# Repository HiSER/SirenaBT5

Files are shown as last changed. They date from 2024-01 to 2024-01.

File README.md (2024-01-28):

### Car music SirenaBT5
Приект выпущен по MIT лицензии, каждый кто использует проект, использует его на свой страх и риск, автор ответственности не несёт.
Проект выпущен как есть, без дальнейшей поддержки.

The project is published under the MIT license, everyone who uses the project uses it at their own peril and risk, the author does not bear responsibility.
The project is being released as is, no future support.

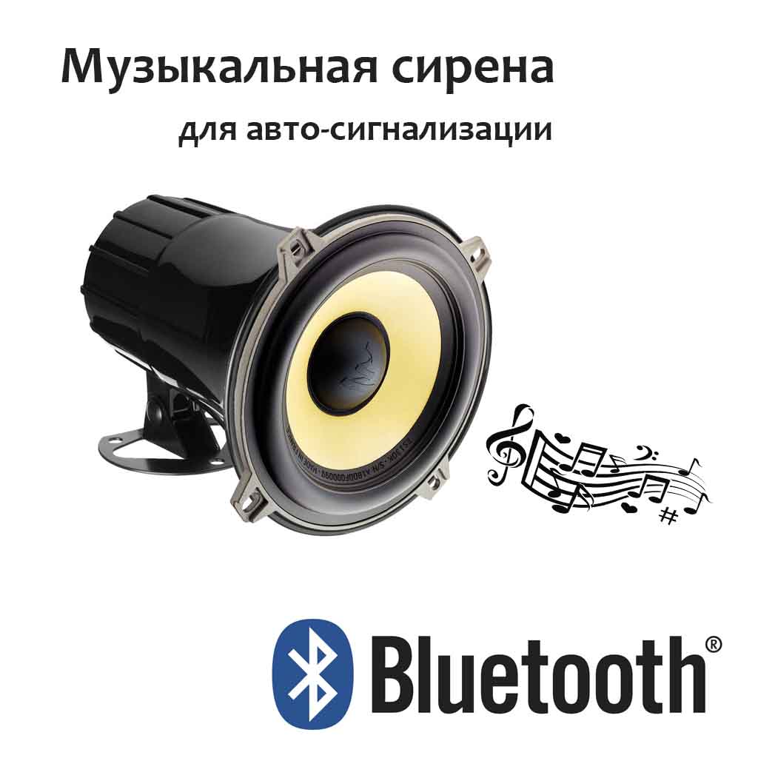
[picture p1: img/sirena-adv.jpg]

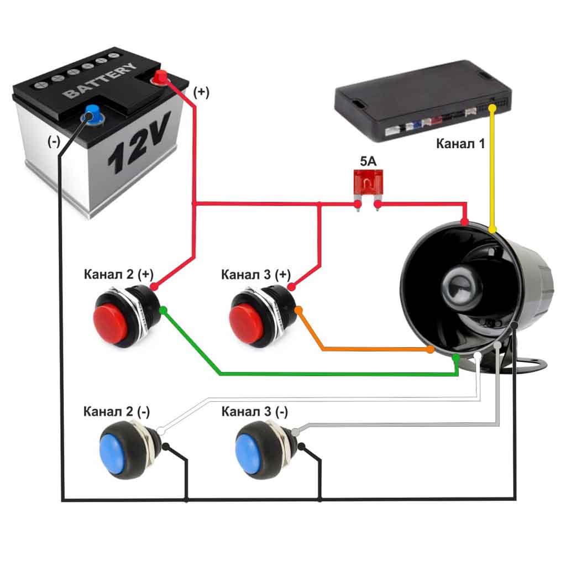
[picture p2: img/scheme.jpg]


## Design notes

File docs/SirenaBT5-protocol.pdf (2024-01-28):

# SirenaBT5

## Описание протокола обмена

### 2 SirenaBT5

Принцип работы

Протокол обмена SirenaBT5 аналогичен протоколу AT. Формат данных текстовой, каждая строка заканчивается символом CRLF. Канал связи работает в полном дуплексе. Некоторые ответы могут приходить без предварительного запроса командой. Команды требовательны к регистру символов. Канал связи BlueTooth профиль SPP-C (виртуальный COM порт). Команды можно отправлять подряд, не дождавшись ответа, буфер составляет 2048 байт.

Формат команды:

[команда][CRLF]

[команда]=[аргументы][CRLF]

Несколько аргументов разделяются символом ;

Формат ответа:

+[команда]:[ответ][CRLF]

Ответ может содержать:

- ключевые слова: OK, ERROR, BUSY, READY, NULL, TRUE, FALSE
- аргументы разделённые символом ;
- ключевое слово совместно с аргументом
- JSON

### 3 SirenaBT5

Список команд

- SPEAK
- PLAY*
- PLAYSTOP*
- LIST*
- GETMELODY*
- SETMELODY*
- DATAMELODY*
- ENDMELODY*
- DELETEMELODY*
- CLEARMELODY*
- GETEVENT*
- SETEVENT*
- DELETEEVENT*
- CLEAREVENT*
- SAVEFS*
- FS
- INFO
- GETCONFIG
- SETCONFIG
- SETBUTTON
- SETMEASURE
- SETPRESSMAX
- SETIDLEMAX
- SETDEVIATION
- PINCODE
- SAVECONFIG

*Команды зависят от состояния файловой системы

### 4 SirenaBT5

Список асинхронных ответов

- +FS
- +EVENT
- +PLAYSTOP

### 5 SirenaBT5

Команда SPEAK

Воспроизведение потокового аудио
Формат потока WAVE 8kHz 8bit, закодирован для передачи в WAVE7.

Команда записывает семплы в буфер и тут же начинает воспроизведение, воспроизведение продолжается до опустошения буфера. В ответе приходит количество записанных семплов в буфер, если количество записанных семплов меньше, чем было отправлено, то необходимо повторно отправить не записанные семплы. Порядок семплов слева на право.

Рекомендуется отправлять семплы пакетами по 1024 байт, размер пакета считается в незакодированном виде.

Отправка производится последовательно запрос/ответ, до тех пор, пока не закончатся аудио данные.

Запрос:

SPEAK=<семплы в кодировке WAVE7>

Ответ:

+SPEAK: {"writed":<записано семплов>}

### 6 SirenaBT5

Команда PLAY

Воспроизведение записанной мелодии
Доступные индексы узнаются командой LIST.

Ответ приходит при начале воспроизведения и конце воспроизведения.

Ответ +PLAYSTOP приходит без запроса.

Запрос:

PLAY =<index>

Ответ:

+PLAY: {"index":<index>}

+PLAYSTOP: {"index":<index>}

### 7 SirenaBT5

Команда PLAYSTOP

Остановить воспроизведение мелодии
Останавливает воспроизведение мелодии.

Если воспроизведения не было, то ответ с числом мелодии не придёт.

Запрос:

PLAYSTOP

Ответ:

+PLAYSTOP:OK

+PLAYSTOP: {"index":<index>}

### 8 SirenaBT5

Команда LIST

Запрос таблиц мелодий и событий
Возвращает массивы индексов мелодий, настроенных событий и максимальный размер таблиц.

Если файловая система не инициализирована, возвращает NULL.

Запрос:

LIST

Ответ:

+LIST:NULL

или

+LIST: {"melody":[],"event":[],"melodyMax":40," eventMax":30}

### 9 SirenaBT5

Команда GETMELODY

Получить информацию о мелодии
Доступные индексы узнаются командой LIST.

Возвращает название мелодии в формате UTF-8 в кодировке BASE64.

Возвращает null, в случае, если мелодия с этим индексом не существует.

Запрос:

GETMELODY=<index>

Ответ:

+GETMELODY:{"index":<index>,"name":"<base64>"}

или

+GETMELODY:{"index":<index>,"name":null}

### 10 SirenaBT5

Команда SETMELODY

Начать запись мелодии
Запрос на начало записи мелодии, параметры:
length | Размер аудио данных от 1 до 1Мб
samples | Дискретизация от 8 до 48kHz
base64 | Название в UTF-8 не более 512 байт, кодировка BASE64
Возвращает индекс мелодии или ошибку:
PARAM | Ошибка в параметрах
BUSY | Уже был запрос на запись
FULL | Нету места в таблице
IO | Сбой ввода/вывода
Запрос:

SETMELODY=<length>;<samples>;<base64>

Ответ:

+SETMELODY:{"index":<index>}

или

+SETMELODY:ERROR;<error>

### 11 SirenaBT5

Команда DATAMELODY

Отправка пакетов данных мелодии
Отправка данных осуществляется пакетами по 512 байт, последний пакет не обязан быть 512 байт. Данные кодируются в BASE64.

Ответ OK означается успешное завершение записи данных, ждёт следующий пакет. END означает конец приёма.

Возможные ошибки:

DATA | Данные более 512 байт или ещё не завершилась прошлая операция
WRITE | Ошибка записи, сбой ввода/вывода
Запрос:

DATAMELODY=<base64>

Ответ:

+DATAMELODY:OK

или

+DATAMELODY:END

или

+DATAMELODY:ERROR;<error>

### 12 SirenaBT5

Команда ENDMELODY

Завершить запись мелодии
Закрывает поток записи мелодии, если поток не был открыт, возвращает FALSE, иначе TRUE.

Запрос:

ENDMELODY

Ответ:

+ENDMELODY:TRUE

или

+ENDMELODY:FALSE

### 13 SirenaBT5

Команда DELETEMELODY

Удалить мелодию

Запрос:

DELETEMELODY=<index>

Ответ:

+DELETEMELODY:{"index":<index>,"delete":<bool>}

### 14 SirenaBT5

Команда CLEARMELODY

Очистить таблицу мелодий

Запрос:

CLEARMELODY

Ответ:

+CLEARMELODY:OK

### 15 SirenaBT5

Команда GETEVENT

Получить информацию о событии
Тип null, означает событие отсутствует.

Запрос:

GETEVENT=<index>

Ответ:

+GETEVENT:<json>

JSON:

index | 0
type | null, cyclic, press, pulse
chIndex | 1
melodyIndex | -1
poweroff | <bool>
pulse | [{}] | До 3х объектов
pulse:
width | 100
count | 1

### 16 SirenaBT5

Команда SETEVENT

Установить или изменить событие
В отличие от SETMELODY, в этой команде контроль над свободными индексами должен производиться в программе.

Параметры:

index | Индекс события
melodyIndex | Индекс мелодии (-1 мелодия не выбрана)
poweroff | 0 – 1
chIndex | 1 – 3
type | null, pulse, cyclic, 1 – 3
| null аналогичен DELETEEVENT
| если число, то задаются типы width и count
width | Ширина импульса
count | Количество импульсов
Запрос:

SETEVENT=<index>;<melodyIndex>;<poweroff>;<chIndex>;<type>[;< width>;<count>[;...]]

Ответ:

+SETEVENT: {"index":<index>,"change":<bool>}

или

+SETEVENT:ERROR;<error>

### 17 SirenaBT5

Команда DELETEEVENT

Сбросить событие

Запрос:

DELETEEVENT=<index>

Ответ:

+DELETEEVENT:{"index":<index>,"delete":<bool>}

### 18 SirenaBT5

Команда CLEAREVENT

Очистить таблицу событий

Запрос:

CLEAREVENT

Ответ:

+CLEAREVENT:OK

### 19 SirenaBT5

Команда SAVEFS

Сохранить таблицы мелодий и событий
Возвращает, TRUE было сохранено, FALSE не удалось сохранить, BUSY файловая система не инициализирована.

Запрос:

SAVEFS

Ответ:

+SAVEFS:TRUE

или

+SAVEFS:FALSE

или

+SAVEFS:BUSY

### 20 SirenaBT5

Команда FS

Состояние файловой системы
READY файловая система готова к операциям ввода/вывода.

BUSY ошибка инициализации файловой системы.

Ответ со значением BUSY может придти без запроса.

Запрос:

FS

Ответ:

+FS:READY

или

+FS:BUSY

### 21 SirenaBT5

Команда INFO

Запрос состояния устройства
Запрос:

INFO

Ответ:

+INFO:<json>

JSON:

fsReady | <bool> | Аналог команды FS
version | 5.0 | Версия программы
build | 1000 | Номер сборки
pincode | "0000" | Аналог команды PINCODE

### 22 SirenaBT5

Команда GETCONFIG

Запрос конфигураций
Настройки 3х каналов в JSON.

Запрос:

GETCONFIG

Ответ:

+GETCONFIG:[{},{},{}]

Объект:

pressMax | <1 - 2000>
idleMax | <1 - 2000>
pulsesMax | <1 - 20>
deviation | <1 - 50>
button | <bool>
measure | <bool>

### 23 SirenaBT5

Команда SETCONFIG

Установка конфигурации
Индекс это номер канала -1, то есть счет с 0.

Значения BOOL задаются цифрами 0-1.

Запрос:

SETCONFIG=<index>;<pressMax>;<idleMax>;<pulsesMax>;<deviation >;<button>;<measure>

Ответ:

+SETCONFIG:{"index":<index>}

### 24 SirenaBT5

Команда SETBUTTON

Установка частичной конфигурации

Запрос:

SETBUTTON=<index>;<button>

Ответ:

+SETBUTTON:{"index":<index>}

### 25 SirenaBT5

Команда SETMEASURE

Установка частичной конфигурации

Запрос:

SETMEASURE=<index>;<measure>

Ответ:

+SETMEASURE:{"index":<index>}

### 26 SirenaBT5

Команда SETPRESSMAX

Установка частичной конфигурации

Запрос:

SETPRESSMAX=<index>;<pressMax>

Ответ:

+SETPRESSMAX:{"index":<index>}

### 27 SirenaBT5

Команда SETIDLEMAX

Установка частичной конфигурации

Запрос:

SETIDLEMAX=<index>;<idleMax>

Ответ:

+SETIDLEMAX:{"index":<index>}

### 28 SirenaBT5

Команда SETPULSESMAX

Установка частичной конфигурации

Запрос:

SETPULSESMAX=<index>;<pulsesMax>

Ответ:

+SETPULSESMAX:{"index":<index>}

### 29 SirenaBT5

Команда SETDEVIATION

Установка частичной конфигурации

Запрос:

SETDEVIATION=<index>;<deviation>

Ответ:

+SETDEVIATION:{"index":<index>}

### 30 SirenaBT5

Команда PINCODE

Запрос и установка пин-кода

Пин-код фиксированной длины 4 символа, символы только числа 0 – 9.
Запрос:

PINCODE

Ответ:

+PINCODE:0000

Запрос:

PINCODE=0000

Ответ:

+PINCODE:OK

### 31 SirenaBT5

Команда SAVECONFIG

Сохранение конфигураций
TRUE конфигурация сохранена, FALSE ошибка сохранения.

Запрос:

SAVECONFIG

Ответ:

+SAVECONFIG:TRUE

или

+SAVECONFIG:FALSE

### 32 SirenaBT5

Ответ +EVENT

Произошло событие на канале
Ответ:

+EVENT:<json>

JSON:

index | 1 – 3 | канал
type | pulse, press, release, cyclic, measure, errMeasure
pulse | [{}] | до 3х объектов
measure | {}
pulse:
width | 100
count | 1

measure:

width | 100
idle | 101

### 33 SirenaBT5

Формат WAVE7

Принцип формата состоит в удалении одного бита из 8 битного семпла и переводе числа 0-127 в строковые данные.

Удаление бита:

Sample7 = Sample8 >> 1;

Перевод в символы ANSI:

0 – 25 | 65 – 90 | (A-Z)
26 – 51 | 97 – 122 | (a-z)
52 – 61 | 48 – 57 | (0-9)
62 – 125 | 192 – 255 | (А-Яа-я)
126 | 43 | (+)
127 | 47 | (/)

### 34 SirenaBT5

Принцип взаимодействия

Буфера приёма и отправки 2048 байт. Символ конца строки CRLF. Таймаут отправки 1000 мс. Таймаут ответа 3000 мс.

Если произошёл таймаут или другая фатальная ошибка при передаче, то следует переподключиться и произвести инициализацию по новой.

Ожидание приёма должно быть асинхронным, а не синхронным ожиданием ответа после отправки.

Контроль таймаута ответа производится следующим способом: есть счетчик выполняемых команд, при каждом запросе команды счетчик инкрементируется и запускается счетчик таймаута. В процедуре приёма производится разбор входящих данных на ответы, каждый ответ декрементируется счетчик команд и перезагружает счетчик таймаута. Как только счетчик команд равен 0 отключает счетчик таймаута. Необходимо учесть, что есть асинхронные ответы не требующие запроса, и в случае если счетчик равен 0, такие ответы не должны декрементировать счетчик команд и перезагружает счетчик таймаута.

### 35 SirenaBT5

Подключение и инициализация

После подключения необходимо отправить команду INFO, если файловая система не готова к работе выдаём сообщение об ошибке и периодически переподключаемся.

Далее запрашиваем таблицы мелодий и событий командой LIST, после ответа запрашиваем информацию о мелодиях и событиях командами GETMELODY и GETEVENT.

Запрашиваем конфигурации командой GETCONFIG.

На этом инициализация закончена, остальные команды отправляются от взаимодействия пользователя с программой.

### 36 SirenaBT5

Запись мелодии

Запрашиваем поток записи командой SETMELODY.

Блокируем приложение и показываем прогресс.

Далее синхронно отправляем данные командой DATAMELODY, до момента получения ответа END.

Закрываем поток ENDMELODY.

Разблокируем приложение.

### 37 SirenaBT5

Потоковое аудио

Отправляются синхронно данные командой SPEAK, в ответе приходит количество записанных данных, не записанные данные нужно отправить повторно. Процедура повторяется, пока данные не будут закончены.

Запись данных с микрофона нужно ограничить 10 секундами.

Нажимается кнопка, производится запись с микрофона до отпускания кнопки или по истечению времени ограничения.

Блокируется кнопки и начинается передача в сирену, по завершению передачи кнопка разблокируется.

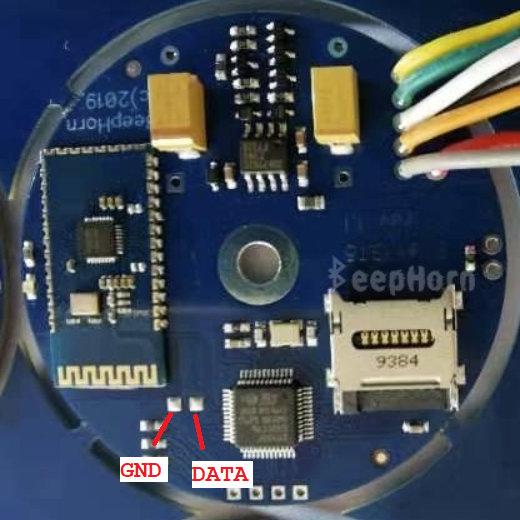
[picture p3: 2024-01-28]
sirena_uart/uart_doc/pinout.png

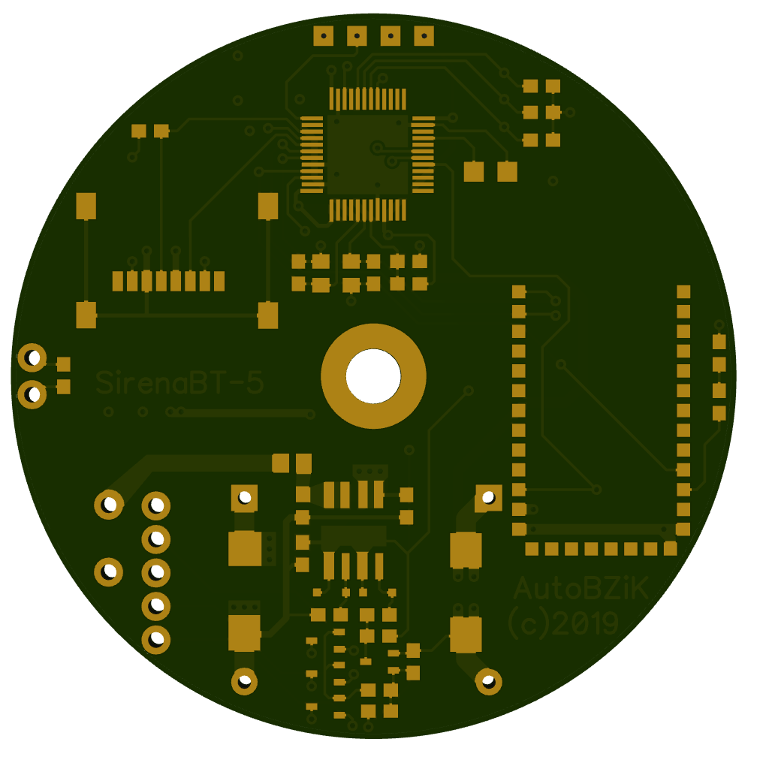
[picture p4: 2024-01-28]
PCB/SirenaBT-5-top.png

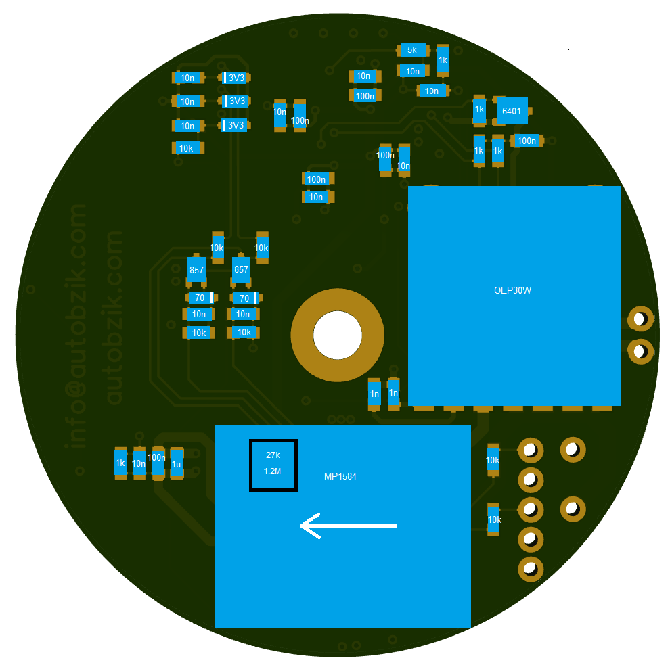
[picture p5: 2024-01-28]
PCB/SirenaBT-5-bottom-nominals.png

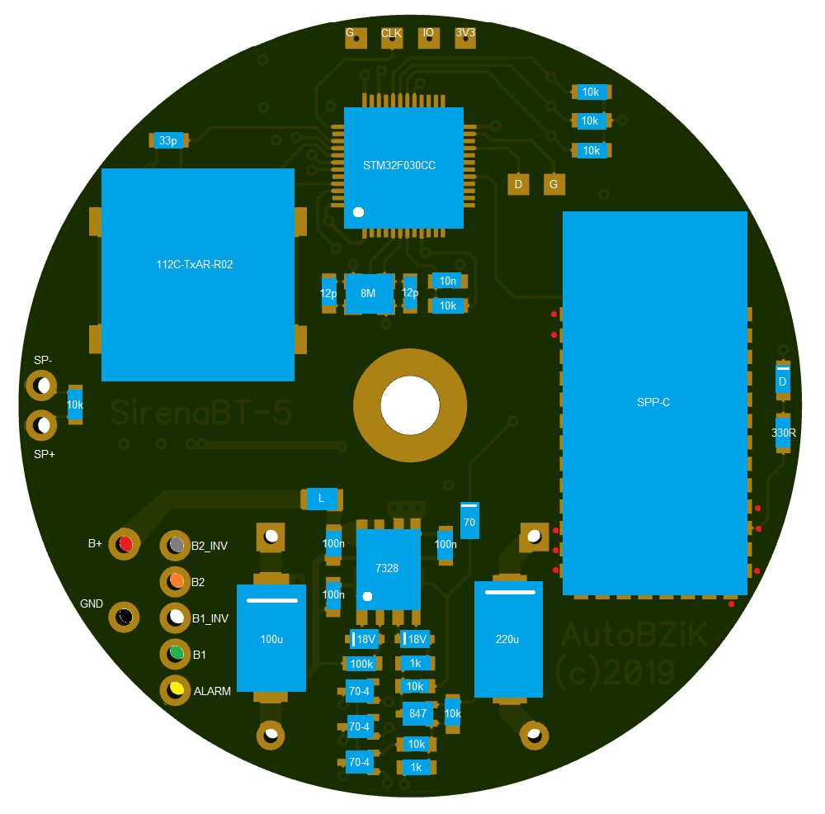
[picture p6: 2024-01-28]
PCB/SirenaBT-5-top-nominals.png

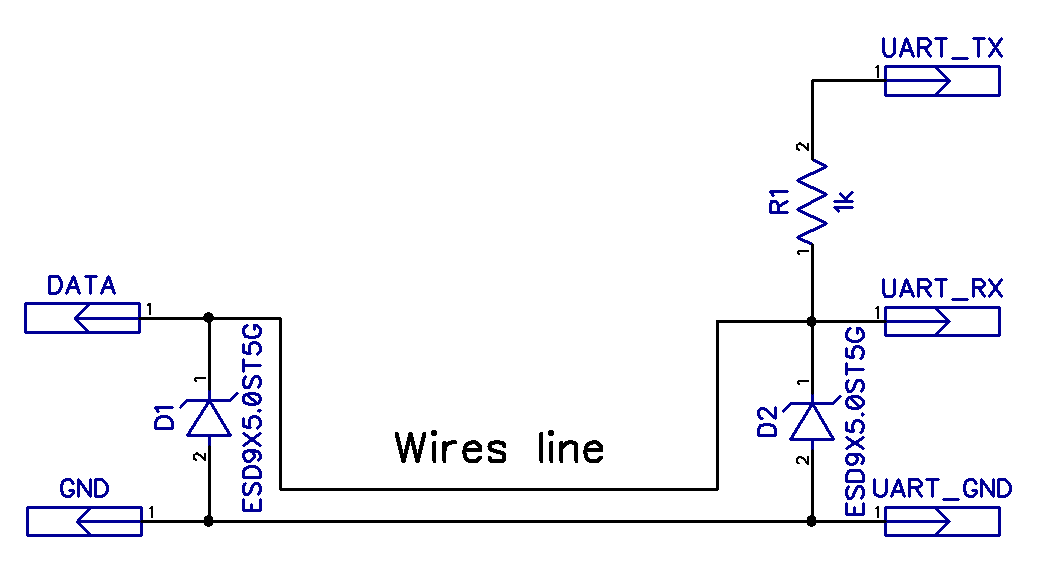
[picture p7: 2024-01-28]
sirena_uart/uart_doc/connect.png

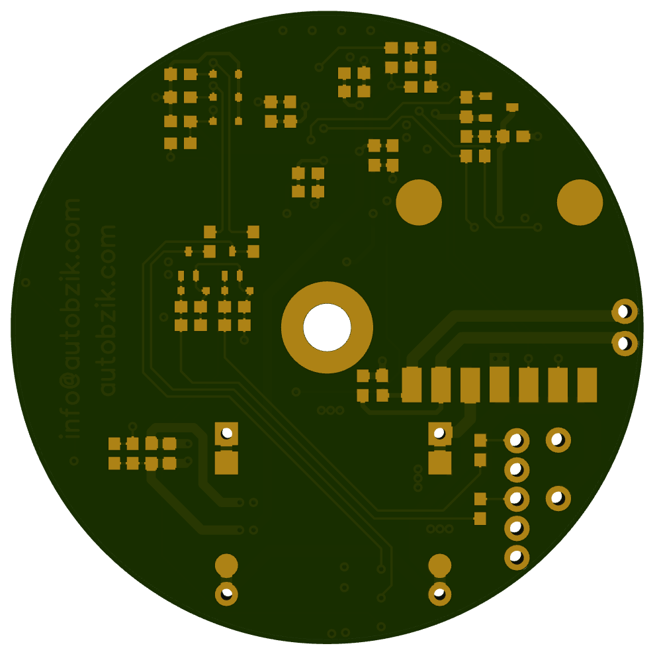
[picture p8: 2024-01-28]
PCB/SirenaBT-5-bottom.png

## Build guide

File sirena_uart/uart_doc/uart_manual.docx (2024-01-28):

Для включение UART режима нужно подключится терминалом по BT и ввести команды.

Устанавливаем приложение Serial Bluetooth Terminal на смартфон.

Будим и сопрягаем сирену по BT.

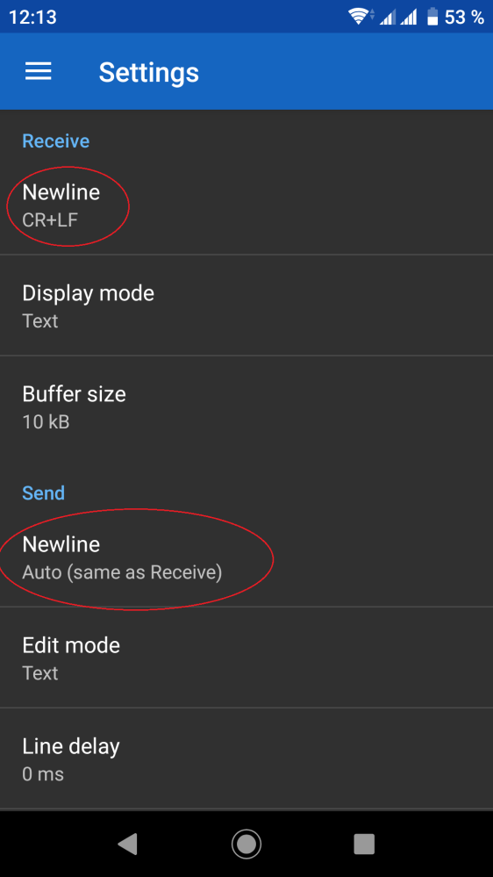
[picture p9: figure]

Открываем приложение и в настройках устанавливаем новую линию CR+LF:

Далее, подключаемся к SirenaBT-5.0 и вводим 2 команды:

SETUART=1

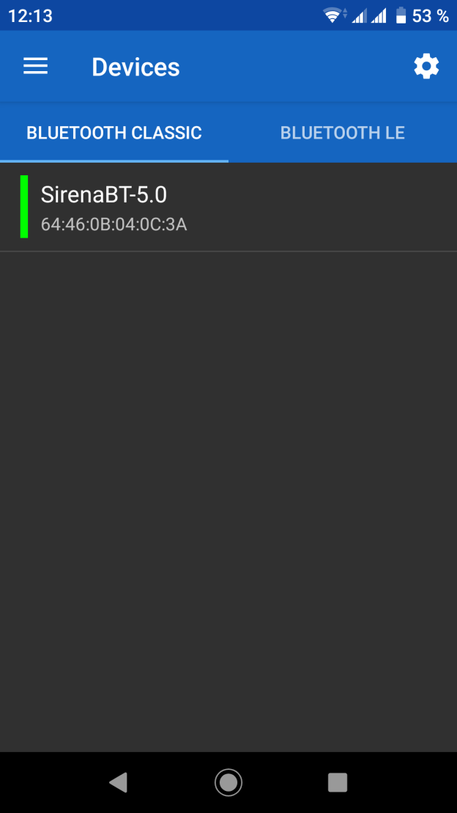
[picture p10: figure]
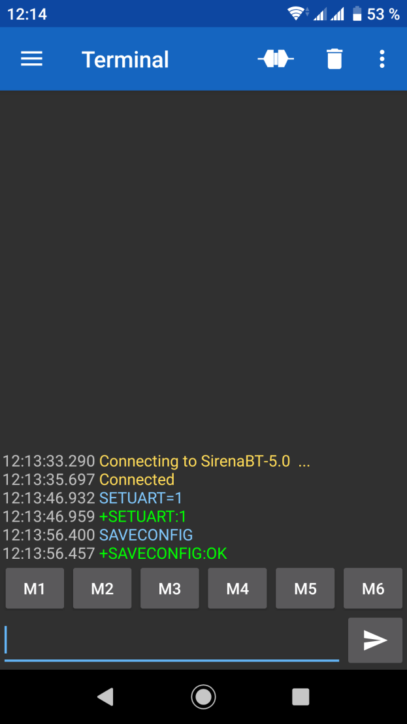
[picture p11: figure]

SAVECONFIG

Теперь можно управлять сиреной через UART.


Подключение к сирене:


Схема для подключения:

Диоды защита от статики, не обязательно устанавливать.

Параметры UART – 19200 бод, 8 бит, 1 стоп бит

Список команд:

AT пустая команда

Ответ: OK

MELODY вывод списка мелодий

Ответ: 0,1,2,…

PLAY=<index> воспроизведение мелодии, index – номер мелодии 0 – 39

Ответ: index или +PLAYSTOP:index

PLAYSTOP остановить воспроизведение

Ответ: OK

Ответ приходит +<имя команды>:<ответ>

Команды и ответы заканчиваются новой линией CR+LF (\r\n)

Чтобы воспроизвести новую мелодию не дожидаясь завершения воспроизведения, требуется выполнить PLAYSTOP, перед PLAY.

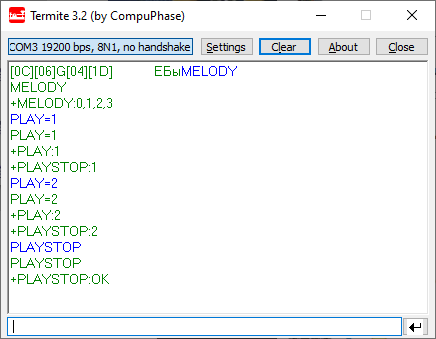
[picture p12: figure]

Перед началом работы нужно пробудить сирену коротким импульсом на 2 или 3 канале, при включении в терминал прилетит мусор, готовность канала можно проверить командой AT.

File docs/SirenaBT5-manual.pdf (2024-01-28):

# SirenaBT5

## Пользовательская инструкция

### 2 SirenaBT5

Технические характеристики

Напряжение питания постоянного тока | 9 – 16В
Ток потребления номинальный (при воспроизведении) | 50мА (1,5А)
Ток потребления пиковый, не более | 4А
Ток потребления в дежурном режиме | 0мкА
Рабочая температура, oC | от -40 до +85
Количество входных каналов | 3
Количество инверсионных каналов | 2
Входное сопротивление каналов, не менее | 10кОм
Интерфейс настройки | BlueTooth
Поддержка разной ширины импульсов | Есть
Переход в дежурный режим, через | 10 мин
Переход в дежурный режим по завершению мелодии | Есть¹
Воспроизведение мелодий из программы | Есть
Воспроизведение голоса из программы | Есть²
Защита от неправильного подключения питания | Есть

1Настраивается в событиях

2Доступно в программе на смартфоне

### 3 SirenaBT5

Схема подключения

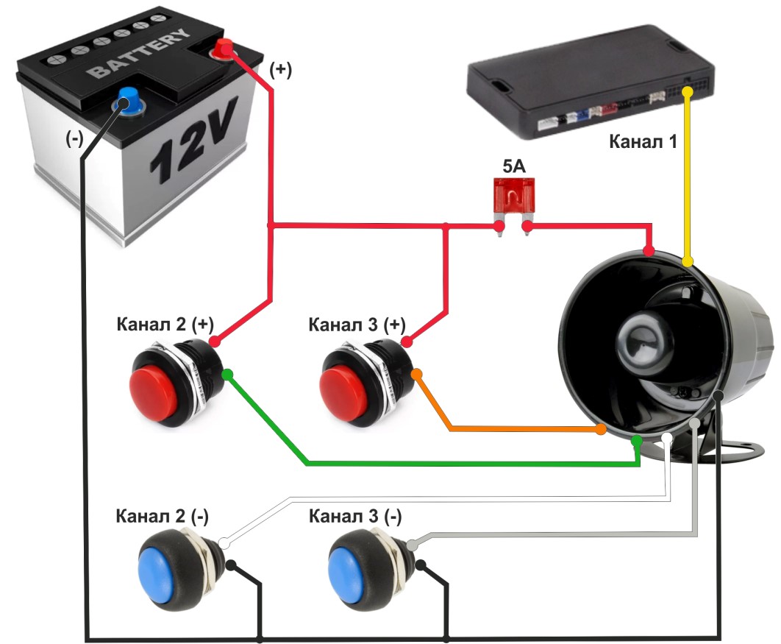
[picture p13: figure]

Предохранитель следует устанавливать рядом с точкой подключения к питанию, а не рядом с сиреной. Предохранитель устанавливается, не только для защиты от возможной неисправности сирены, но и для защиты от повреждения линии питания.

Канал 1 подключается к сигнализации, можно перенастроить для подключения кнопки, в этом случае не отрабатываются импульсы.

### 4 SirenaBT5

Схема пайки проводов к плате

Динамик и питание:

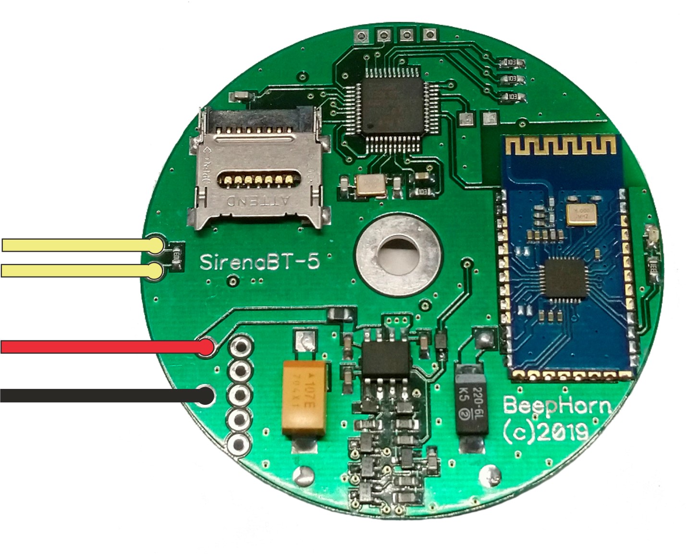
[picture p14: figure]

Каналы:

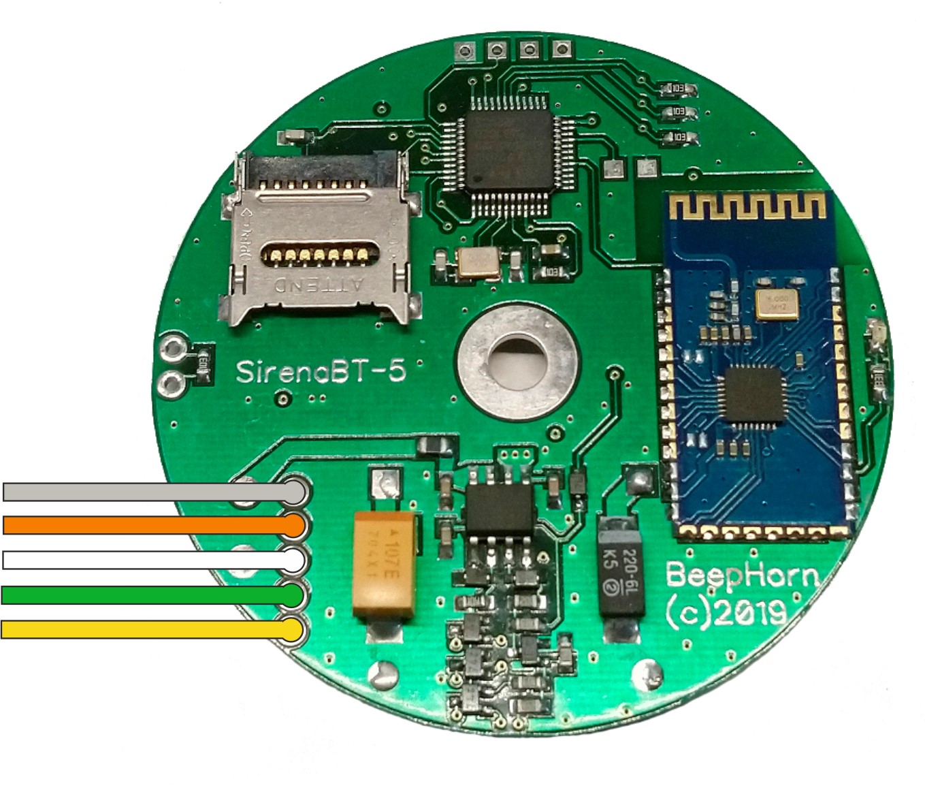
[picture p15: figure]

### 1. Micro SD карта любого класса от 128Mb до 32Gb 2. Динамик с сопротивлением, не менее 4 Ом

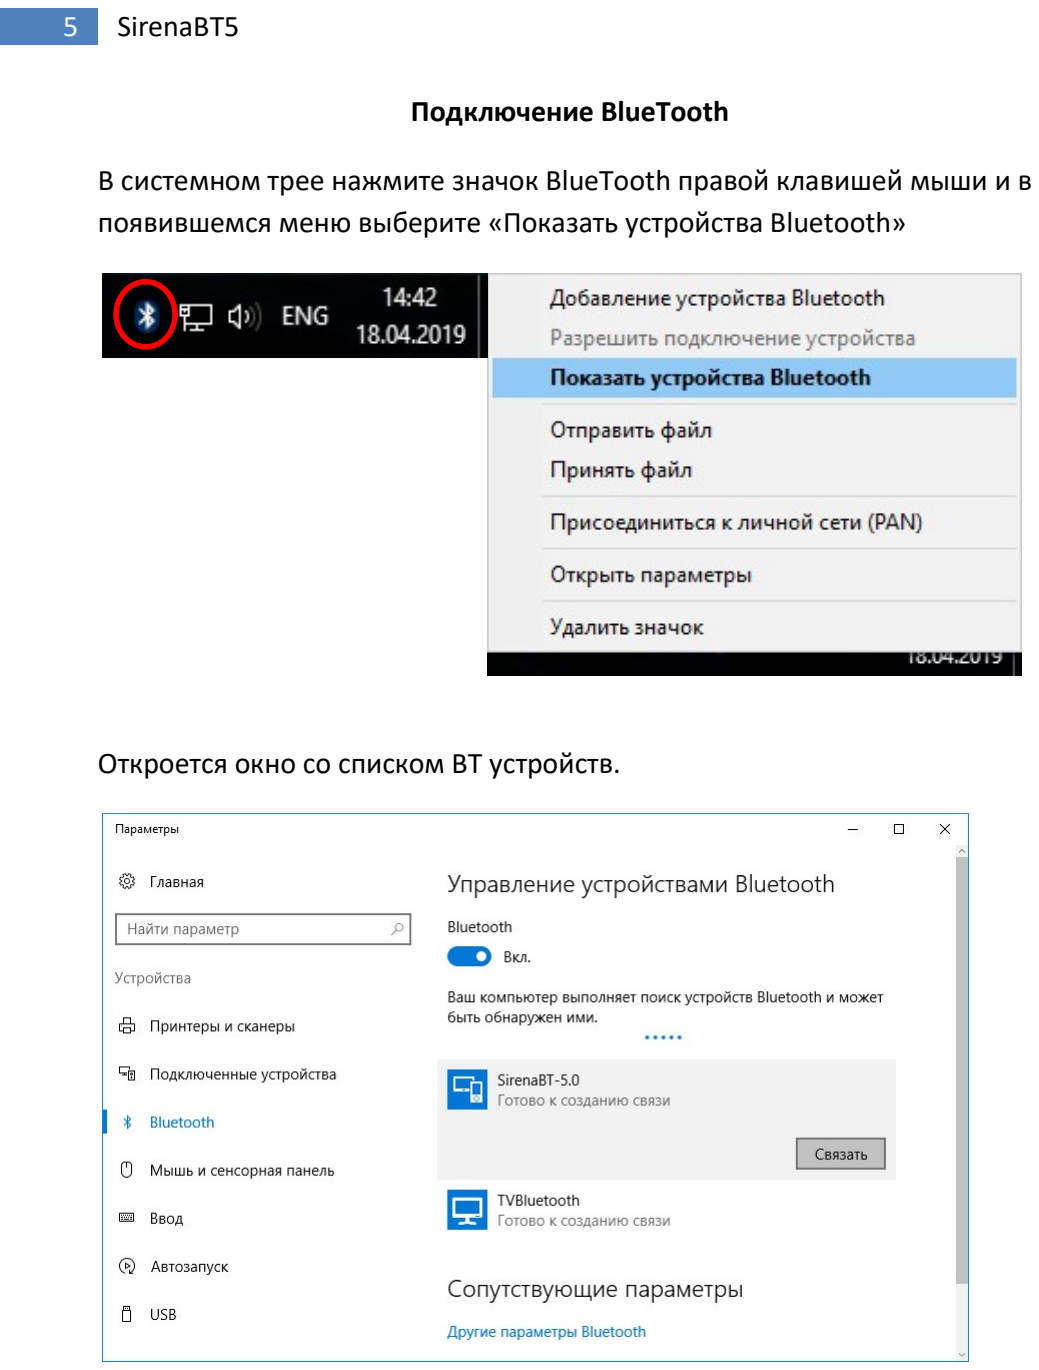
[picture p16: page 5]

### 5 SirenaBT5

Подключение BlueTooth

В системном трее нажмите значок BlueTooth правой клавишей мыши и в появившемся меню выберите «Показать устройства Bluetooth»

Откроется окно со списком BT устройств.

### 6 SirenaBT5

Выведите сирену из дежурного режима, событием на любом канале. В случае, если на всех каналах настроено событие с переходом в дежурный режим по завершению мелодии, то необходимо удерживать любой канал до момента подключения программой к сирене.

При установленном соединении с программой, сирена не будет переходить в дежурный режим.

Дождитесь появления устройства SirenaBT-5.0 в списке, выберите устройство и нажмите «Связать». В появившемся окне введите пин-код и дождитесь сопряжения с устройством.

Теперь, можно открывать программу для настройки.

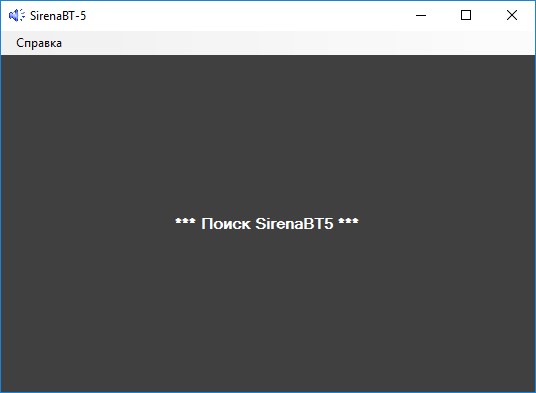
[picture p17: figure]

### 7 SirenaBT5

Возможные проблемы при подключении программы

Ошибки выдаваемые программой:

Ни одного устройства не найдено

Не было сопряжено устройство
Не удалось подключиться

Сирена находится в дежурном режиме или обесточена
Не удалось открыть порт

Какая-то программа использует порт
Таймаут ответа

Не удалось отправить данные

Произошел сбой передачи данных
Файловая система не инициализировалась

Отсутствует или испорчена SD-карта
Ошибка сохранения

Ошибка загрузки мелодии

Произошел сбой при работе с SD-картой

Некоторые ошибки могут возникать при сильных помехах или сбое драйвера. Если после нескольких попыток подключения, не удаётся подключиться, удалите устройство из сопрягаемых и снова сопрягите.

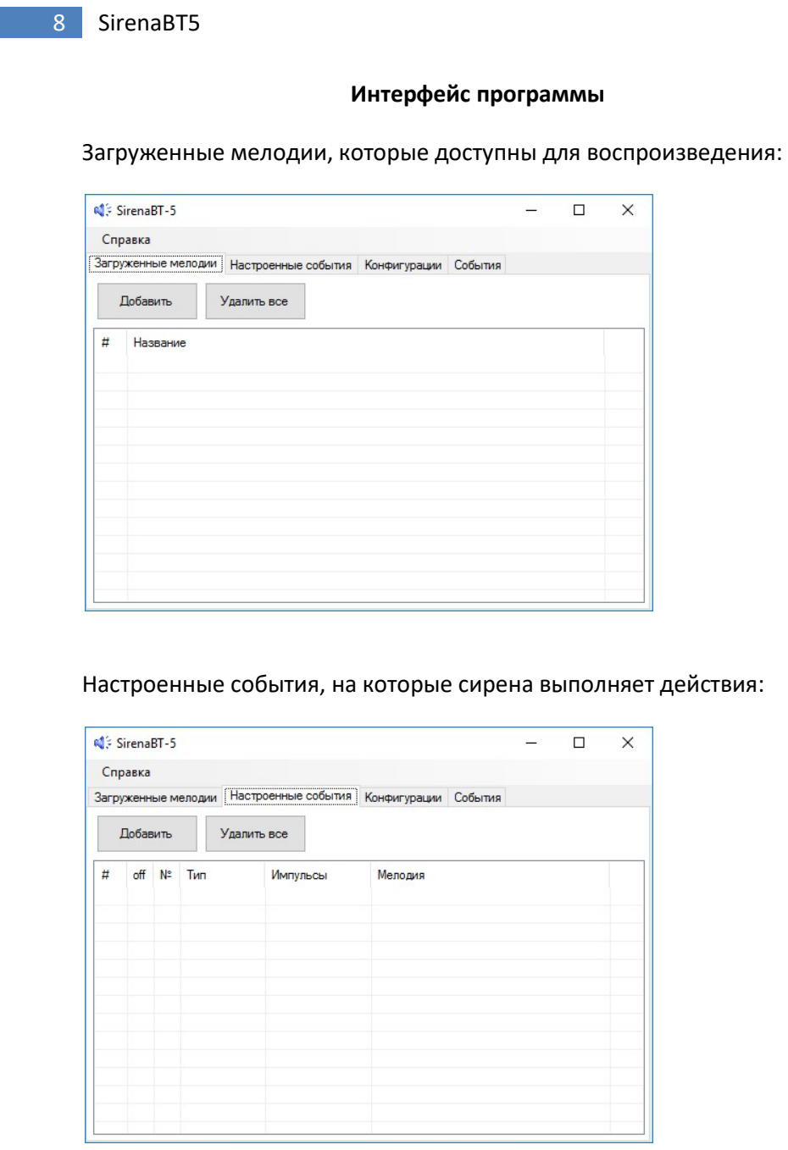
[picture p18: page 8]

### 8 SirenaBT5

Интерфейс программы

Загруженные мелодии, которые доступны для воспроизведения:

Настроенные события, на которые сирена выполняет действия:

### 9 SirenaBT5

Конфигурации сирены:

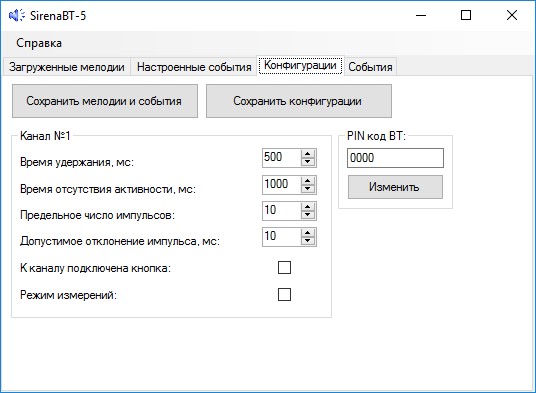
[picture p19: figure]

Параметры изменяются в реальном времени, цифровые значения применяются переключением поля ввода или по клавише ENTER.

Пин-код состоит из 4х цифр и применяется по кнопке «Изменить». Новый пин-код будет присвоен только после перезагрузки сирены. Нужно удалить сопрягаемое устройство и снова сопрячь.

Сохранить мелодии и события

Сохраняет таблицу мелодий и событий.
Сохранить конфигурации

Сохраняет конфигурации канала и пин-код.

### 10 SirenaBT5

Время удержания

Минимальное время удержания канала, после которого сирена определяет событие «удержание». Если были зафиксированы импульсы, этот параметр не учитывается.
Время отсутствия активности

Максимальное время не активности канала после импульсов, в это время также входит ширина импульса, после которого считается окончание пачки импульсов.
Предельное число импульсов

Максимальное число импульсов, после которых сирена определяет событие «циклический».
Допустимое отклонение импульса

Отклонение ширины импульса, например: при допустимом отклонении 10 мс, импульс шириной от 90 до 110 будет принадлежать настроенному событию с импульсами 100 мс.
К каналу подключена кнопка

Канал в режиме кнопки, импульсы не используются. В этом режиме измерения не доступны.
Режим измерений

Режим измерения параметров импульсов, определяет «время удержания» и «время отсутствия активности». Не доступен в режиме кнопки.

Перезагрузкой считается переход в дежурный режим или обесточивание сирены. До перезагрузки необходимо сохранить изменения в сирене.

### 11 SirenaBT5

События в реальном времени:

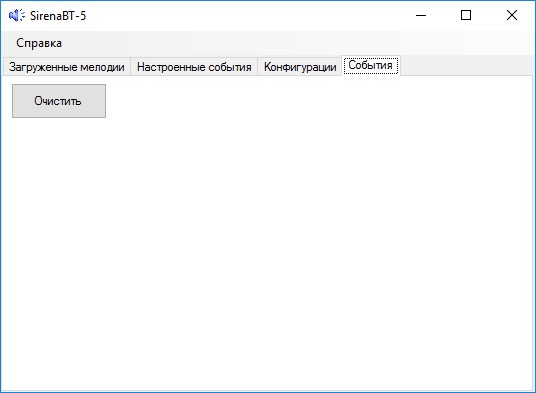
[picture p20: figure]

Здесь отображаются зафиксированные события сиреной, которые можно будет настроить или оценить правильность определения импульсов.

Также, здесь отображаются параметры замеров, когда канал в режиме измерений.

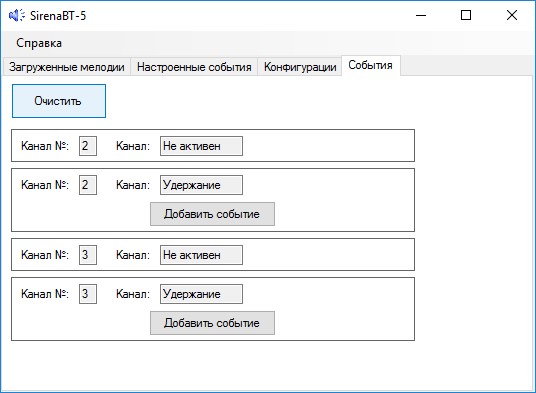
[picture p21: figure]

### 12 SirenaBT5

Загрузка мелодий

Мелодии следует положить в папку «melody» рядом с программой.

Формат мелодии WAVE 8–48kHz 8bit, рекомендуется использовать дискретизацию 24kHz и уровень звука -1.5db.

Во вкладке «Загруженные мелодии» нажимаем кнопку «Добавить» и выбираем мелодию:

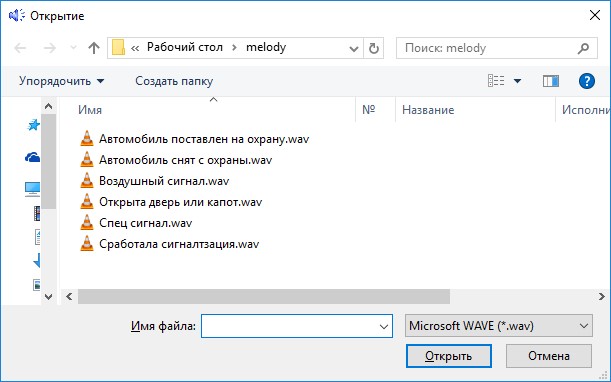
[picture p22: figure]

Ждём загрузки мелодии:

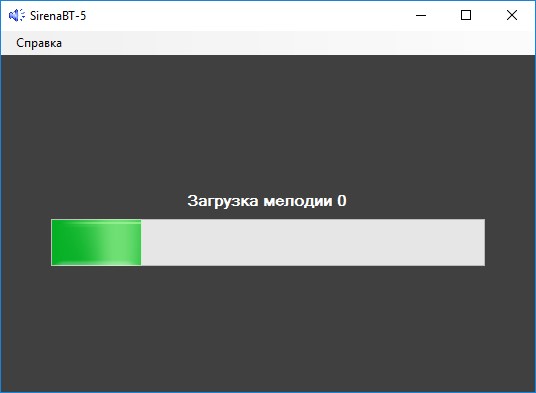
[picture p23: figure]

### 13 SirenaBT5

Как только мелодия загрузится, она появится в списке, также, её сразу можно воспроизвести для проверки:

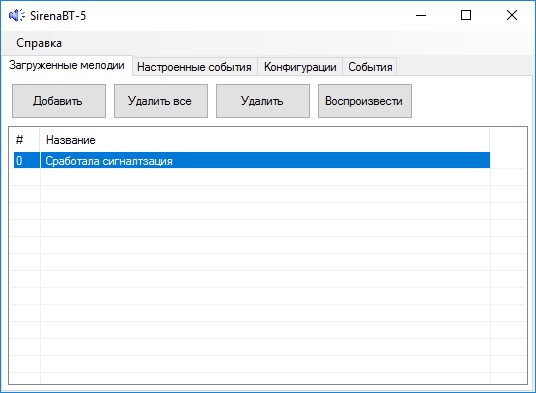
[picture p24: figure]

После загрузки мелодий нужно перейти на вкладку «Конфигурации» и произвести «Сохранить мелодии и события».

### 14 SirenaBT5

Настройка времени удержания и не активности

Установите канал в режим измерения и перейдите во вкладку «События».

Теперь нужно инициировать все возможные импульсные события от сигнализации: открывание, закрывание, поиск, первый уровень датчика удара и прочие.

В списке будут появляться замеры, необходимо выбрать замер с самым большим числом удержания и отсутствием активности, эти цифры нужно занести в поля во вкладке «Конфигурации».

Отключите режим измерений и перейдите во вкладку «События».

Очистите список и повторите события от сигнализации.

Если всё определяется правильно, настройте события.

### 15 SirenaBT5

Настройка событий

Во вкладке «Настроенные события» нажимаем кнопку «Добавить» или во вкладке «События» выбираем событие и нажимаем кнопку «Добавить событие».

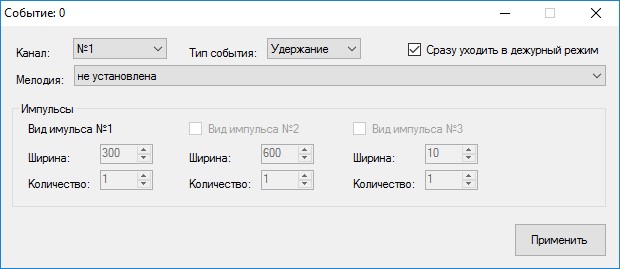
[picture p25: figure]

Канал

Канал которому присвоено событие.
Тип события

«Удержание» – происходит на кнопках или на сигнализации во время тревоги. «Циклический» – происходит при тревоге у сигнализаций, которые, сигналят клаксоном. «Импульс» – пачка импульсов от сигнализации.
Сразу уходить в дежурный режим

Переходить в ждущий режим, после конца воспроизведения мелодии события. Рекомендуется отключать этот режим на одном из каналов 2, 3 и на событие открывание автомобиля.
Мелодия

Мелодия из списка загруженных мелодий. Если мелодия не установлена, воспроизводится штатный звук. Для отключения события нужно вставить пустую мелодию (то есть короткий фрагмент с тишиной).

### 16 SirenaBT5

Импульсы

Сирена разделяет входные пачки импульсов до 3х видов ширины. Соответственно, на 3 вида ширина/количество. Остальные пачки будут отброшены. Пачки нумеруются по порядку 1, 2, 3.

После применения событие появится в списке:

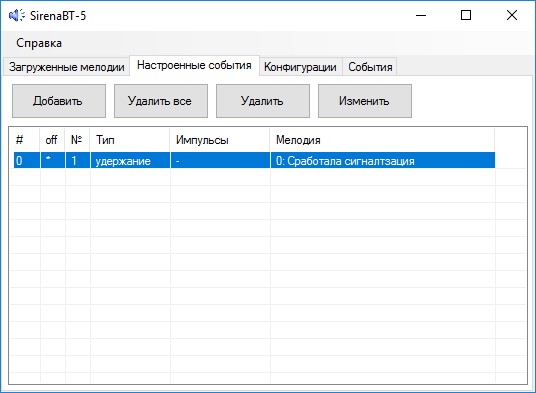
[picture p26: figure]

После настройки событий нужно перейти на вкладку «Конфигурации» и произвести «Сохранить мелодии и события».

Проверку настроек можно производить без сохранений и подключенной программой в реальном времени.

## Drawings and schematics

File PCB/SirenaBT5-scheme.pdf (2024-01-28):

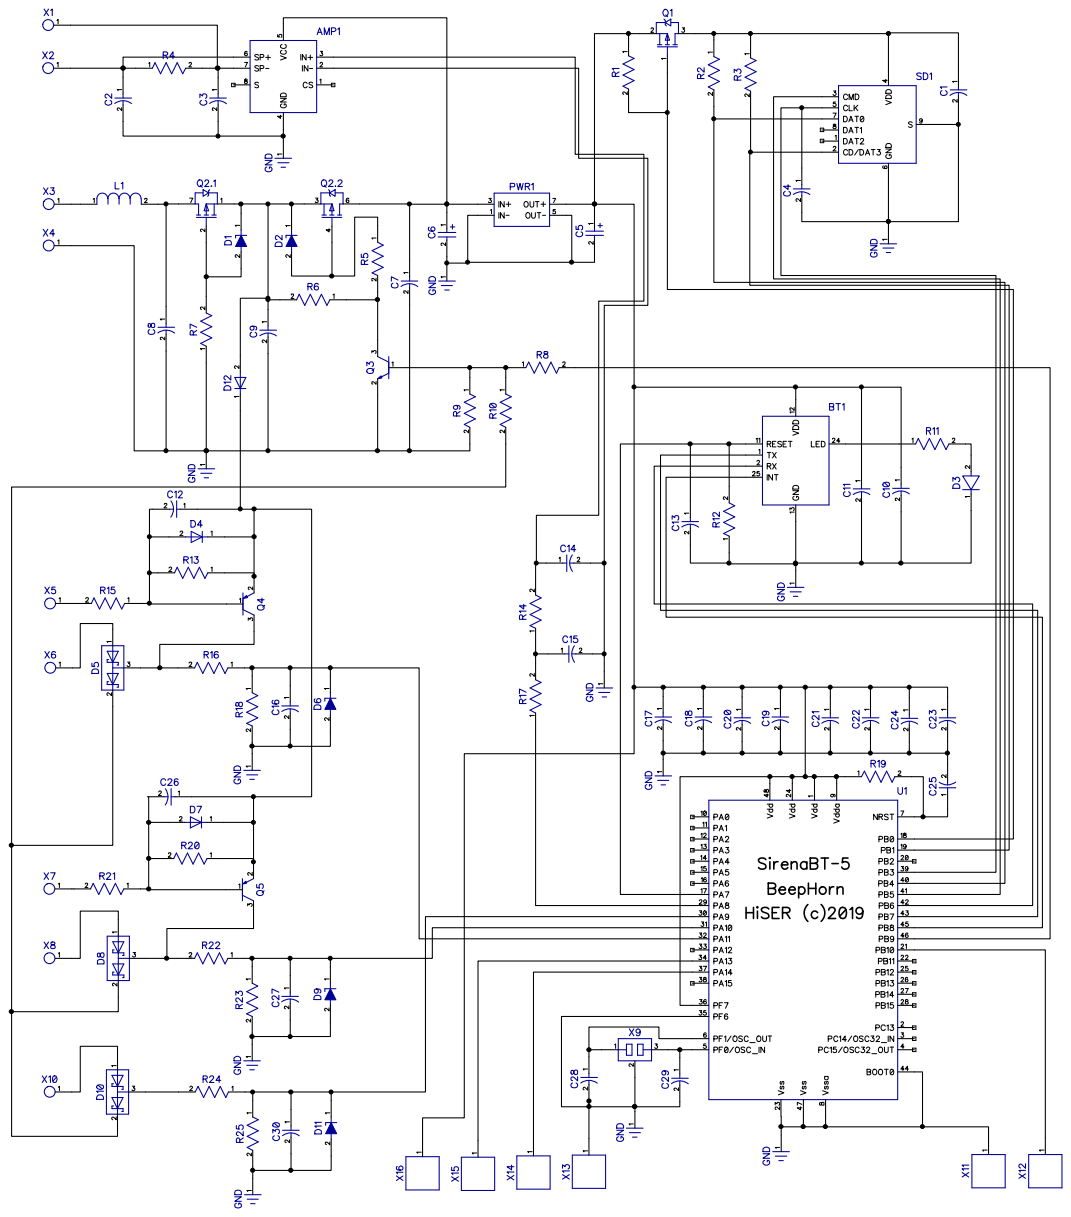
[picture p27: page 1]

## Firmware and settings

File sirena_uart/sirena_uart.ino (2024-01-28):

/**
 * Add library AltSoftSerial
 * TX		9
 * RX		8
 * WakeUP	7
 * LED		13
 * Debug baud 115200
 */

#define WAKEUP		7
#define LED			13


#define DEBUG		0
#define NOTICE		1
#define DEBUG_BAUD	115200



/* Play */

#include <AltSoftSerial.h>

AltSoftSerial playSerial;

#define PLAY_BAUD			19200
#define MLD_MIN				0
#define MLD_MAX				39
#define UART_BUFFER_SIZE	126

byte playIndex;
bool isAnswer;
bool isPlay;
bool isRepeat;
char playBuffer[UART_BUFFER_SIZE + 1];
byte playLength;

void playWakeUp()
{
	digitalWrite(WAKEUP, HIGH);
	delay(10);
	digitalWrite(WAKEUP, LOW);
}

void playStart(byte index, bool repeat = false)
{
	if (index < MLD_MIN || index > MLD_MAX)
	{
		#if NOTICE == 1
		Serial.print("playStart: error index ");
		Serial.println(index);
		#endif
		return;
	}
	if (isPlay)
	{
		#if NOTICE == 1
		Serial.println("playStart collision");
		#endif
		return;
	}
	playWakeUp();
	#if NOTICE == 1
	Serial.print("playMelody: ");
	Serial.println(index);
	#endif
	playIndex = index;
	isRepeat = repeat;
	playSerial.print("PLAY=");
	playSerial.println(playIndex);
	isPlay = true;
	digitalWrite(LED, HIGH);
}

void playStop()
{
	isPlay = false;
	isRepeat = false;
}

void getPlayMelody()
{
	playWakeUp();
	#if NOTICE == 1
	Serial.println("Query melody");
	#endif
	playSerial.println("MELODY");
}

void playInit()
{
	playSerial.begin(PLAY_BAUD);
	pinMode(WAKEUP, OUTPUT);
	digitalWrite(WAKEUP, LOW);
	pinMode(LED, OUTPUT);
	digitalWrite(LED, LOW);
	isAnswer = false;
	isRepeat = false;
	isPlay = false;
	playLength = 0;
	playBuffer[0] = '\0';
}

void playAnswer(char* cmd, char* value)
{
	if (strcmp(cmd, "PLAY") == 0)
	{
		#if NOTICE == 1
		Serial.print("Play started: ");
		Serial.println(value);
		#endif
	}
	else if (strcmp(cmd, "PLAYSTOP") == 0)
	{
		isPlay = false;
		digitalWrite(LED, LOW);
		if (strcmp(value, "OK") != 0)
		{
			#if NOTICE == 1
			Serial.print("Play stoped: ");
			Serial.println(value);
			#endif
			if (isRepeat)
			{
				#if NOTICE == 1
				Serial.print("Play repeat: ");
				Serial.println(value);
				#endif
				playSerial.print("PLAY=");
				playSerial.println(value);
			}
		}
	}
	else
	{
		#if NOTICE == 1
		Serial.print("playAnswer: ");
		Serial.print(cmd);
		Serial.print(" = ");
		Serial.println(value);
		#endif		
	}
}

void playRoutine()
{
	byte data;
	if (isAnswer)
	{
		while (playSerial.available())
		{
			data = playSerial.read();
			if (data == '\n')
			{
				if (playLength > 0)
				{
					if (playBuffer[playLength - 1] == '\r')
					{
						playLength--;
						playBuffer[playLength] = '\0';
					}
					if (playLength > 0)
					{
						char* cmd = playBuffer;
						char* value = strstr(playBuffer, ":");
						if (value == NULL)
						{
							char nullValue = 0;
							value = &nullValue;
						}
						else
						{
							(*value++) = '\0';
						}
						playAnswer(cmd, value);
					}
				}
				isAnswer = false;
				playLength = 0;
				playBuffer[0] = '\0';
			}
			else if (playLength < UART_BUFFER_SIZE)
			{
				playBuffer[playLength++] = data;
				playBuffer[playLength] = '\0';
			}
			else
			{
				#if DEBUG == 1
				Serial.println("Play overflow buffer");
				#endif
			}
		}
	}
	else
	{
		data = playSerial.read();
		if (data == '+')
		{
			isAnswer = true;
			#if DEBUG == 1
			Serial.println("Play detected answer");
			#endif
		}
	}
}

/* ------------------------------ */



/* Key */

byte keyOld;
byte melodyHigh;
byte melodyRepeat;

void setMelodyLow(byte low)
{
	#if DEBUG == 1
	Serial.print("setMelodyLow: ");
	Serial.println(low);
	#endif
	playStart(melodyHigh + low, melodyRepeat);
}

void setMelodyHigh(byte high)
{
	melodyHigh = high * 10;
	#if DEBUG == 1
	Serial.print("setMelodyHigh: ");
	Serial.println(melodyHigh);
	#endif
}

void setMelodyRepeat(bool repeat)
{
	#if NOTICE == 1
	Serial.print("setMelodyRepeat: ");
	Serial.println(repeat);
	#endif
	melodyRepeat = repeat;
}

void keyInit()
{
	keyOld = 255;
	melodyHigh = 0;
	melodyRepeat = false;
}

void keyRoutine()
{
	byte key = Serial.read();
	if (key != keyOld)
	{
		if (key >= '0' && key <= '9')
		{
			setMelodyLow(key - '0');
		}
		else
		{
			switch (key)
			{
				case 'A':
				case 'a':
					setMelodyHigh(0);
					break;
				case 'B':
				case 'b':
					setMelodyHigh(1);
					break;
				case 'C':
				case 'c':
					setMelodyHigh(2);
					break;
				case 'D':
				case 'd':
					setMelodyHigh(3);
					break;
				case 'M':
				case 'm':
					getPlayMelody();
					break;
				case 'R':
				case 'r':
					setMelodyRepeat(true);
					break;
				case 'N':
				case 'n':
					setMelodyRepeat(false);
					break;
				case 'S':
				case 's':
					playStop();
					break;
			}
		}
		keyOld = key;
	}
}

/* ------------------------------ */



/* Main */

void setup()
{
	Serial.begin(DEBUG_BAUD);
	playInit();
	keyInit();
}

void loop()
{
	keyRoutine();
	playRoutine();
}

/* ------------------------------ */

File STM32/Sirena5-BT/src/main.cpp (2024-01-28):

#include <main.hpp>
#include <timer.hpp>
#include <dbg.hpp>
#include <call.hpp>
#include <encoders.hpp>
#include <bt.hpp>
#include <amp.hpp>
#include <ch.hpp>
#include <sirena.hpp>
#include <sd.hpp>
#include <fs.hpp>
#include <config.hpp>
#include <remapVect.h>

void callBootCallback(__UNUSED void* param)
{
	CONFIG::DeInit();
	FS::DeInit();
	SD::DeInit();
	BT::DeInit();
	AMP::DeInit();
	CH::DeInit();
	CALL::DeInit();
	TIMER::DeInit();
	DBG::DeInit();
	SIRENA::DeInit();

	RCC_APB2PeriphClockCmd(RCC_APB2Periph_USART1, DISABLE);
	//RCC_APB1PeriphClockCmd(RCC_APB1Periph_USART3, DISABLE);
	//RCC_AHBPeriphClockCmd(RCC_AHBPeriph_GPIOA, DISABLE);
	//RCC_AHBPeriphClockCmd(RCC_AHBPeriph_GPIOB, DISABLE);
	//RCC_AHBPeriphClockCmd(RCC_AHBPeriph_DMA1, DISABLE);
	RCC_APB2PeriphClockCmd(RCC_APB2Periph_SPI1, DISABLE);
	RCC_APB2PeriphClockCmd(RCC_APB2Periph_TIM1, DISABLE);
	RCC_APB2PeriphClockCmd(RCC_APB2Periph_TIM15, DISABLE);
	RCC_APB2PeriphClockCmd(RCC_APB2Periph_TIM16, DISABLE);
	RCC_APB2PeriphClockCmd(RCC_APB2Periph_TIM17, DISABLE);

	USART3->BRR = 0xFEFE;

	callBoot();
}


char b[512];
TIMER* t;
int i;
int h;

void testThread(void* p __UNUSED);
void nextTest();
void endTest();
void startTest();

void testThread(void* p __UNUSED)
{
	if (SD::busy(h))
	{
		CALL::setImmediate(testThread);
	}
	else if (SD::error(h))
	{
		SD::clear(h);
		DBGF("TEST: error read %i", i);
	}
	else
	{
		SD::clear(h);
		i++;
		nextTest();
	}
}

void nextTest()
{
	if (i == 2048)
	{
		endTest();
	}
	else
	{
		h = SD::read(i, &b, 512);
		if (h == -1)
		{
			DBGF("TEST: error handle %i", i);
		}
		else
		{
			CALL::setImmediate(testThread);
		}
	}
}

void endTest()
{
	int e = t->get();
	int b = i * 512;
	DBGF("TEST: readed %i, time %i, %i kb*s", b, e, (b / e));
	delete(t);
}

void startTest()
{
	DBGP("TEST: start");
	t = new TIMER();
	t->set();
	i = 0;
	nextTest();
}

void main(void)
{
	FLASH_SetLatency(FLASH_Latency_1);
	FLASH_PrefetchBufferCmd(ENABLE);

	IWDG_ReloadCounter();

	DBG::Init();
	DBGP(BUILD);

	TIMER::Init();
	CALL::Init();
	CH::Init();
	AMP::Init();
	BT::Init();
	SD::Init();
	FS::Init();
	SIRENA::Init();

	CONFIG::Init();
	CH::Start();

#define IWDG_RELOAD ((40000 / 256) * IWDG_TIME_SECOND)
#if IWDG_RELOAD > 4095
#error IWDG_RELOAD > 4095, change IWDG_TIME_SECOND
#endif
	IWDG_WriteAccessCmd(IWDG_WriteAccess_Enable);
	IWDG_SetPrescaler(IWDG_Prescaler_256);
	IWDG_SetReload(IWDG_RELOAD);
	IWDG_ReloadCounter();
	IWDG_Enable();
#undef IWDG_RELOAD

	//startTest();

	LOOP
	{
		IWDG_ReloadCounter();
		CALL::Thread();
	}
}
